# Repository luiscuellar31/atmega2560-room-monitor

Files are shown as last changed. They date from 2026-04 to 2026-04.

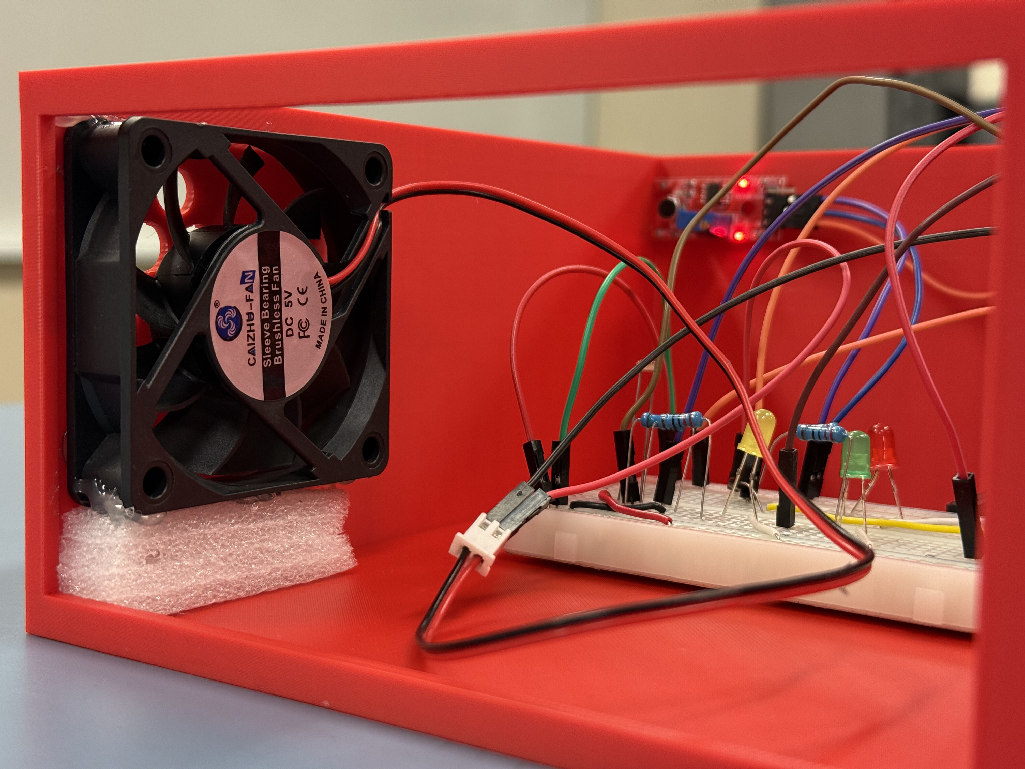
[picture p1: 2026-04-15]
img/monitor-box-fan.jpg

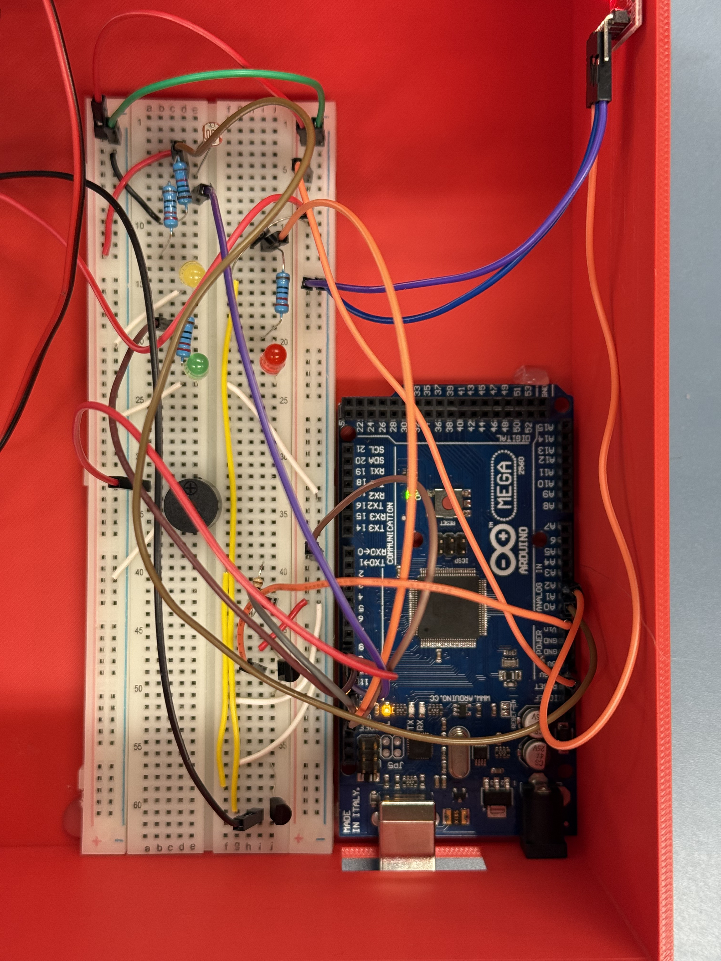
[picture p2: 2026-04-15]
img/monitor-box-up-zoom.jpg

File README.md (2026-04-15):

# ATmega2560 Smart Room Monitor

A simple embedded monitoring system built on the ATmega2560 using AVR Assembly.

## Overview

This project monitors environmental conditions in a small room or study-area model using three analog sensors:

- LM35 temperature sensor
- LDR light sensor
- KY-038 analog sound sensor

According to the detected conditions, the system activates different outputs:

- Red warning LED for high temperature
- Yellow warning LED for low light
- Green warning LED for sound events
- 5V cooling fan
- Active buzzer alarm

## Project Objective

The objective of this project was to design and implement an embedded room-monitoring prototype using the ATmega2560 and AVR Assembly, integrating analog sensing and actuator control under predefined alarm conditions.

This work was developed as part of my Embedded Systems course project.

## Main Features

- Reads three analog sensors through the ADC
- Controls LEDs, fan, and buzzer directly from the microcontroller
- Built almost entirely in AVR Assembly
- Works as a standalone embedded system without requiring a PC during operation

## System Logic

### Temperature
If temperature exceeds the configured threshold:
- Red LED turns on
- Fan turns on

### Light
If the environment is dark:
- Yellow LED turns on

### Sound
If a strong sound event is detected:
- Green LED turns on

To improve event visibility, the sound indicator now uses a short hold window:
- After a valid sound event, the green LED remains active briefly even if the next sample falls below threshold.

### Alarm Conditions
- If **three abnormal conditions** are active at the same time, the buzzer sounds intermittently while active condition LEDs remain on
- If **zero, one, or two abnormal conditions** are active, the buzzer stays off

## Hardware Used

- Arduino Mega 2560 / ATmega2560
- LM35
- LDR
- KY-038
- Active 5V buzzer
- 5V fan
- 2N2222 transistor
- 1N4007 diode
- LEDs
- Resistors
- Breadboard and jumper wires

## ADC Channels

- `A0` -> LM35
- `A1` -> LDR
- `A2` -> KY-038 analog output

## Output Pins

- `D12` -> Red temperature LED
- `D11` -> Fan control
- `D10` -> Yellow light warning LED
- `D9`  -> Green sound warning LED
- `D8`  -> Buzzer

## Notes

- Presentation files are available in [`docs/`](docs/).
- Build/reference photos are available in [`img/`](img/).
- The printable enclosure models are available in [`3d/`](3d/).
- The LDR was used as the sensor selected for the technical explanation of non-linear behavior.
- Threshold values were adjusted experimentally during testing.
- The sound sensor responds better to sharp nearby acoustic events than to continuous speech.
- Current firmware includes a short noise hold (`HOLD_RUIDO`) to avoid losing brief sound events between ADC cycles.

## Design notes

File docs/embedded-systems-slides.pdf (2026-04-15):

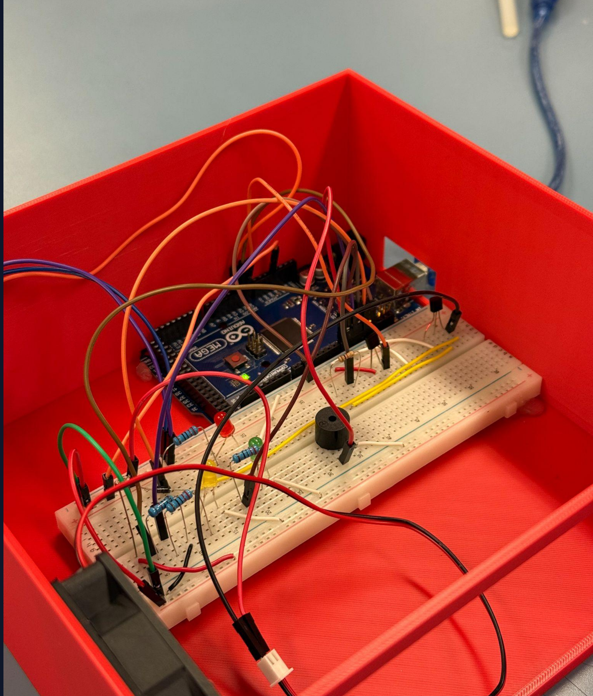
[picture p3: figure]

# Sistema de monitoreo ambiental con ATmega2560

Proyecto de sensores y actuadores programado en ensamblador AVR

Monitoreo de temperatura, iluminación y sonido.

Activación de LEDs, ventilador y buzzer ante condiciones específicas.

▹

▹

Luis Enrique Sánchez Cuellar Erick Daniel Alanis Inocencio

El proyecto busca emular una solución real de monitoreo ambiental usando el ATmega2560 y programación en ensamblador AVR.

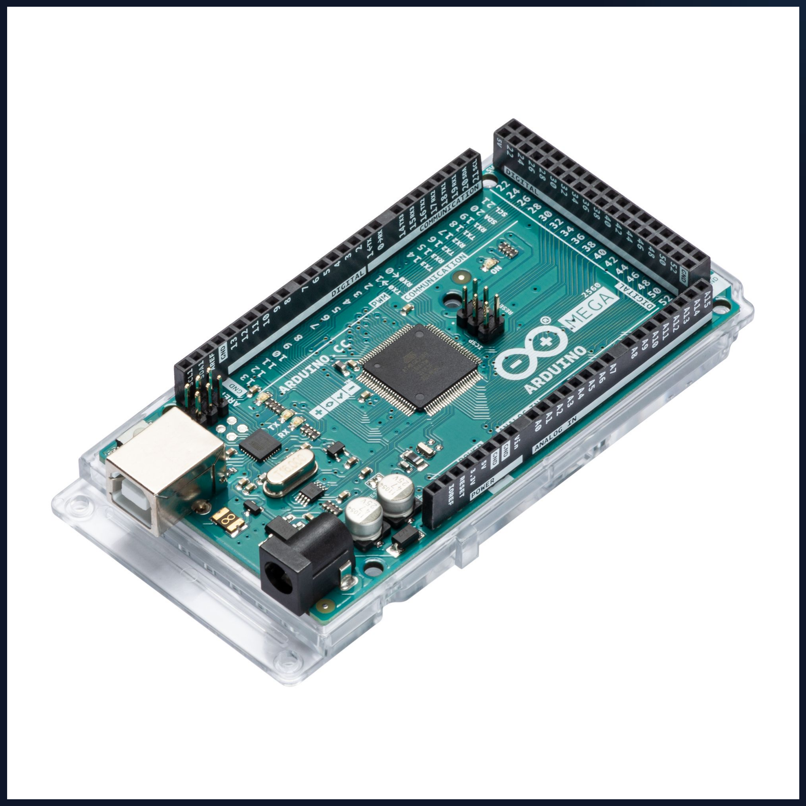
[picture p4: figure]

Diseñar un sistema embebido capaz de monitorear condiciones ambientales de una maqueta o zona de estudio.

Detectar tres variables analógicas del entorno:

Activar salidas de advertencia y respuesta automática según las condiciones medidas.

▹

▹

▹

Temperatura
Iluminación
Perturbaciones acústicas

•
•
•

# Objetivo del proyecto

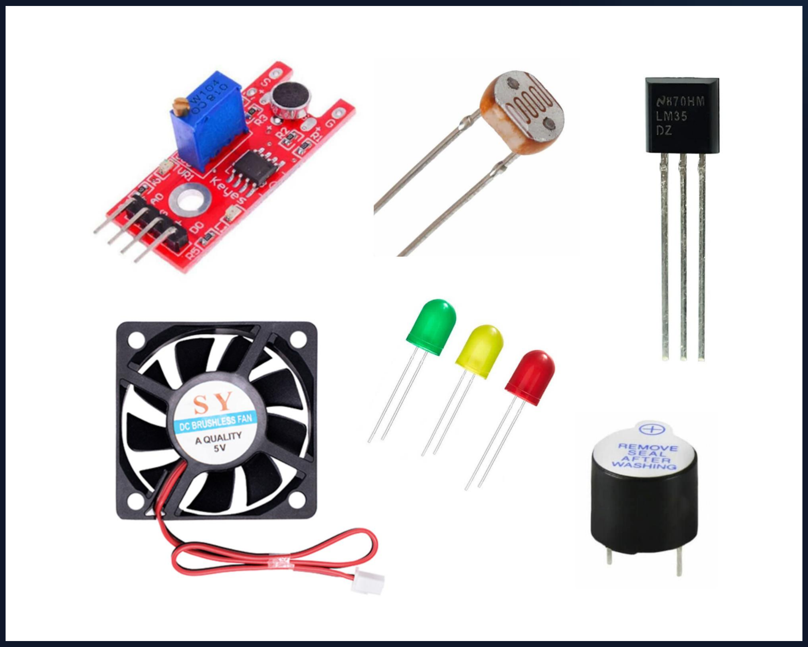
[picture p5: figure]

Sensores analógicos

Actuadores

- LM35 → temperatura
- LDR → iluminación
- KY-038 (salida AO) → perturbaciones acústicas
- LED verde → indicación de evento sonoro
- LED amarillo → indicación de oscuridad
- LED rojo → indicación de temperatura alta
- Ventilador 5V → respuesta ante temperatura alta
- Buzzer activo 5V → alarma crítica

# Sensores y actuadores utilizados

El sistema utiliza el ADC del ATmega2560 para convertir señales analógicas a valores digitales y compararlas con umbrales.

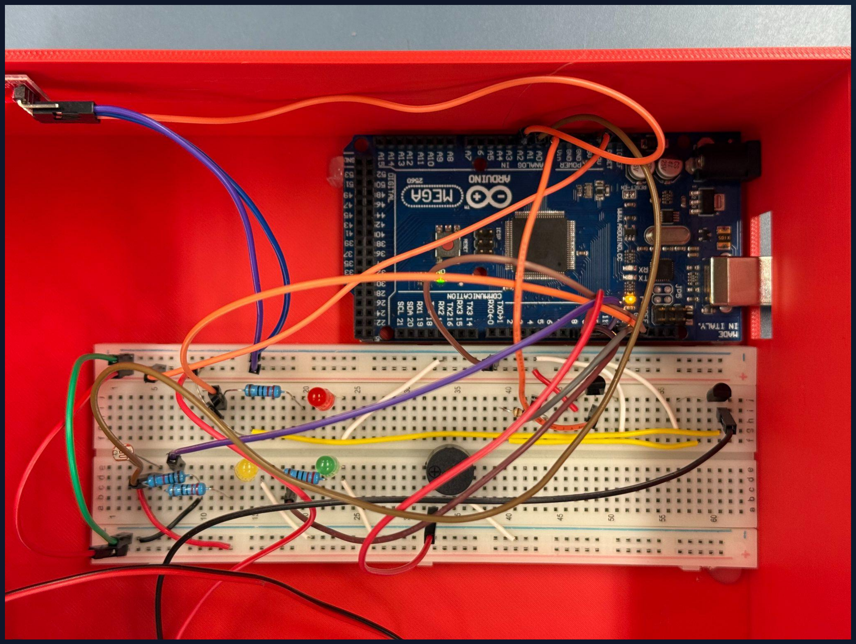
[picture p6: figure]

Entradas analógicas

# Conexión de sensores y salidas al ATmega2560

- A0 → LM35 - A1 → LDR - A2 → KY-038 (AO)

Salidas digitales

- D12 → LED de temperatura
- D11 → ventilador
- D10 → LED de oscuridad
- D9 → LED de ruido
- D8 → buzzer

El sistema utiliza el ADC del ATmega2560 para convertir señales analógicas en valores digitales y compararlas con umbrales definidos experimentalmente.

# Lógica de funcionamiento

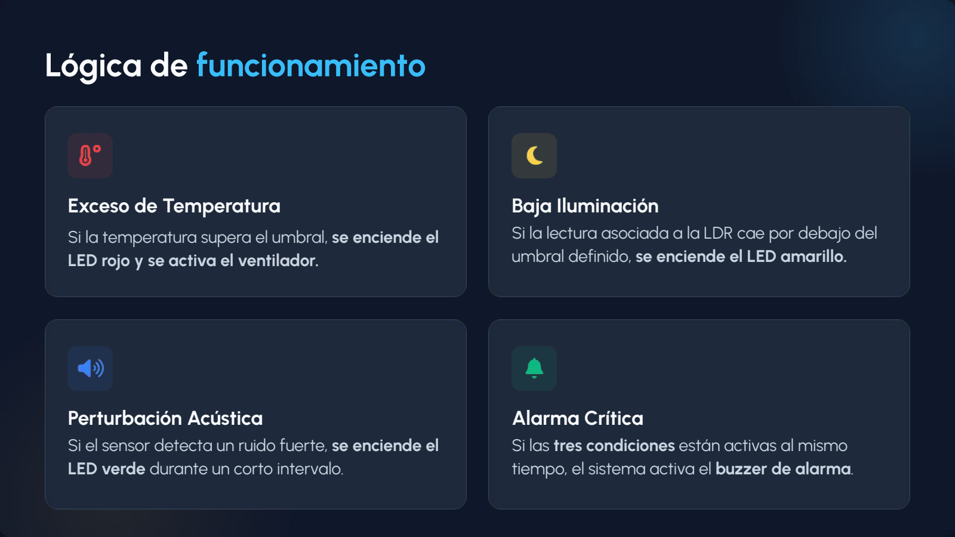
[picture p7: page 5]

Exceso de Temperatura
Si la temperatura supera el umbral, se enciende el LED rojo y se activa el ventilador.

Baja Iluminación
Si la lectura asociada a la LDR cae por debajo del umbral definido, se enciende el LED amarillo.

Perturbación Acústica
Si el sensor detecta un ruido fuerte, se enciende el LED verde durante un corto intervalo.

Alarma Crítica
Si las tres condiciones están activas al mismo tiempo, el sistema activa el buzzer de alarma.

# Descripción y comportamiento no lineal de una LDR

Sensor analógico empleado para detectar condiciones de iluminación. Integrado al ATmega2560 mediante un divisor de voltaje.

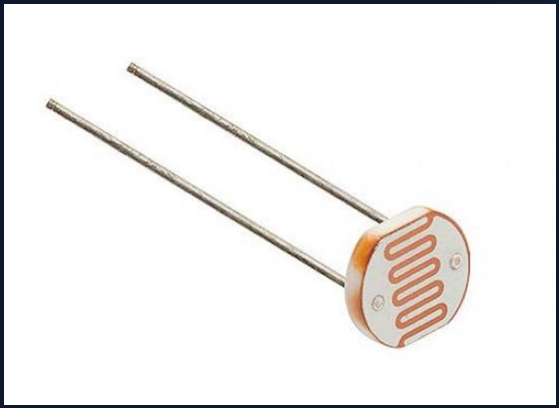
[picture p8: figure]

Una LDR (Light Dependent Resistor) o fotorresistencia es un componente cuya resistencia eléctrica depende de la luz que recibe.

Cuando la iluminación aumenta, su resistencia disminuye.

Cuando la iluminación disminuye, su resistencia aumenta.

Se utiliza para detectar cambios de iluminación de forma sencilla en sistemas y circuitos electrónicos.

▹

▹

▹

▹

# ¿Qué es una LDR?

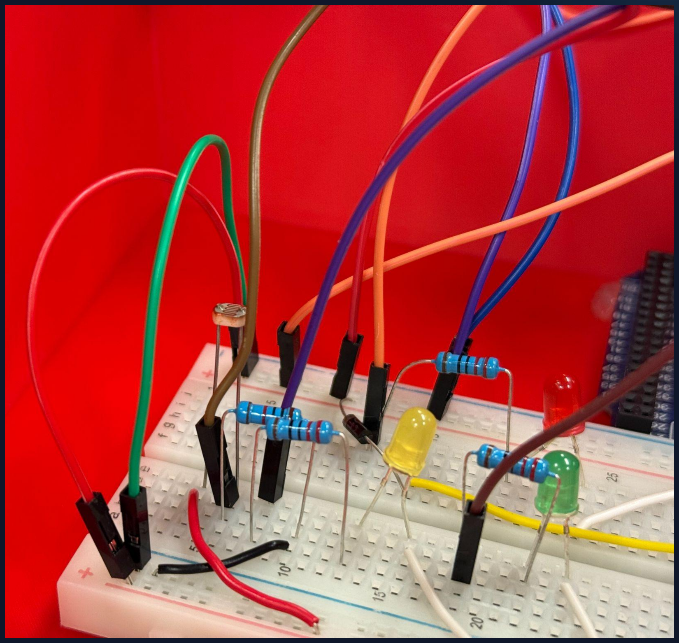
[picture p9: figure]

En el proyecto, la LDR se conectó en un divisor de voltaje con una resistencia fija de 10 kΩ.

El nodo intermedio del divisor se conectó a la entrada analógica A1 del ATmega2560.

El ADC del microcontrolador mide el voltaje resultante y lo compara con un umbral.

▹

▹

▹

# Principio del funcionamiento

De esta forma, el sistema puede detectar condiciones de baja iluminación a partir de la lectura del ADC.

▹

# Modelo eléctrico de la LDR en el circuito

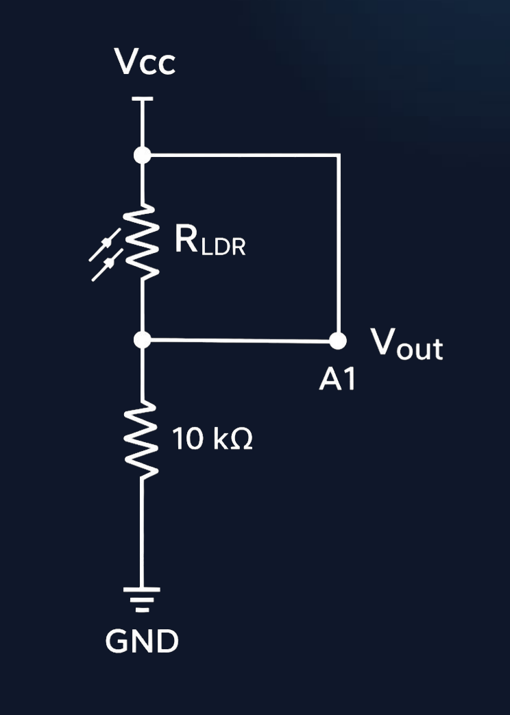
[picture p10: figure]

- La LDR no se mide directamente como resistencia.
- Se integra en un divisor de voltaje junto con una resistencia fija de 10 kΩ.
- El voltaje del nodo intermedio se conecta al pin A1 del ATmega2560.
- Así, las variaciones de resistencia de la LDR se transforman en variaciones de voltaje medibles por el ADC.

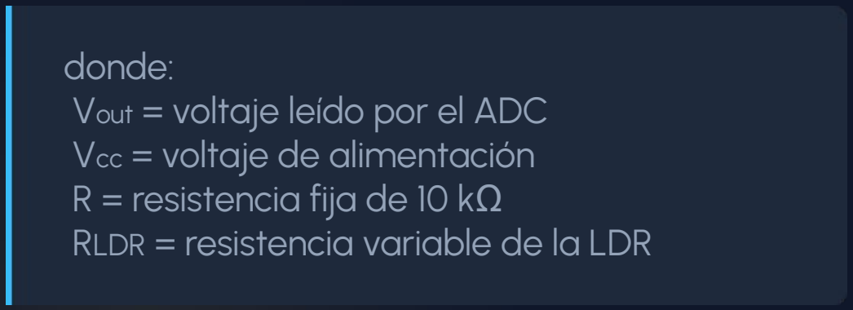
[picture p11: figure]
donde: Vout = voltaje leído por el ADC Vcc = voltaje de alimentación R = resistencia fija de 10 kΩ RLDR = resistencia variable de la LDR

La no linealidad del sensor obliga a ajustar experimentalmente el umbral de detección dentro del proyecto.

- La resistencia de una LDR no varía linealmente con la iluminación.
- En forma aproximada, su comportamiento puede modelarse mediante una relación de potencia:

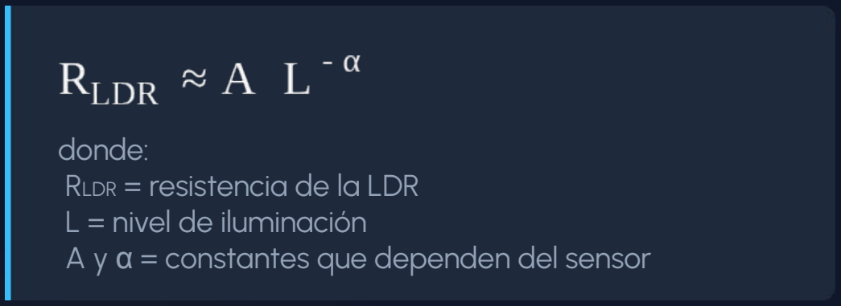
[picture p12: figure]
donde: RLDR = resistencia de la LDR L = nivel de iluminación

A y α = constantes que dependen del sensor

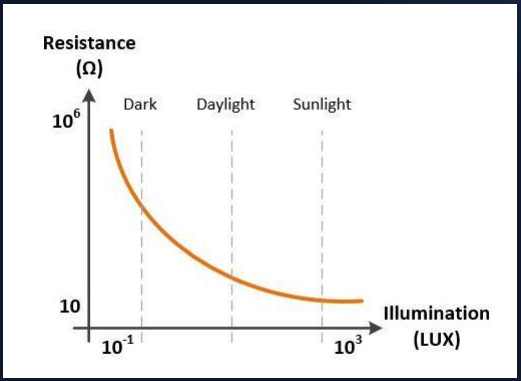
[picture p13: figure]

Esta ecuación muestra que la resistencia disminuye cuando la
iluminación aumenta, pero siguiendo una curva, no una recta.
Por ello, cambios iguales de luz no producen cambios iguales de resistencia ni de voltaje.
Debido a esta no linealidad, el umbral de activación del sistema tuvo que ajustarse experimentalmente.

▹

▹

# Ecuación y comportamiento no lineal de la LDR

# Comportamiento real en

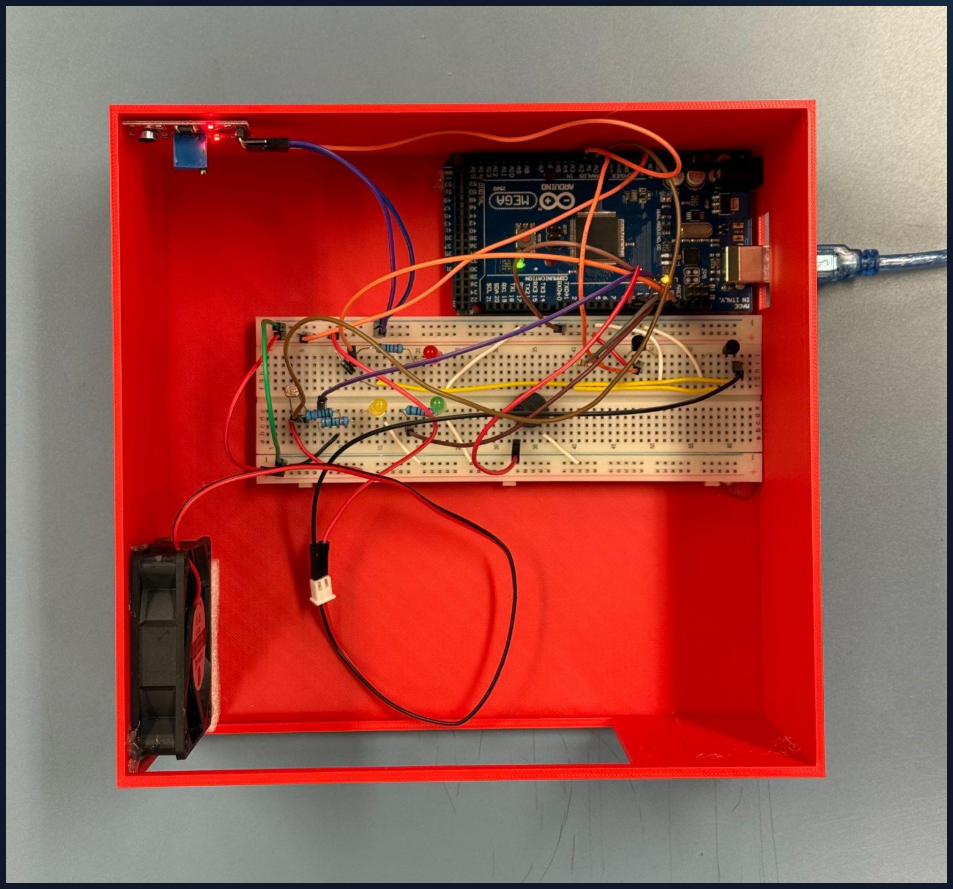
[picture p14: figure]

# el proyecto

En las pruebas del proyecto, la LDR respondió claramente a cambios de luz del entorno.

Con luz intensa (ej. flash del celular), la lectura cambió notablemente.

Al cubrir el sensor o cerrar la tapa de la maqueta, el sistema detectó la oscuridad y encendió el LED amarillo.
La respuesta dependió de factores físicos como:
- dirección de la luz,
- distancia de la fuente,
- cobertura parcial del sensor.

▹

▹

▹

▹

# Conclusión

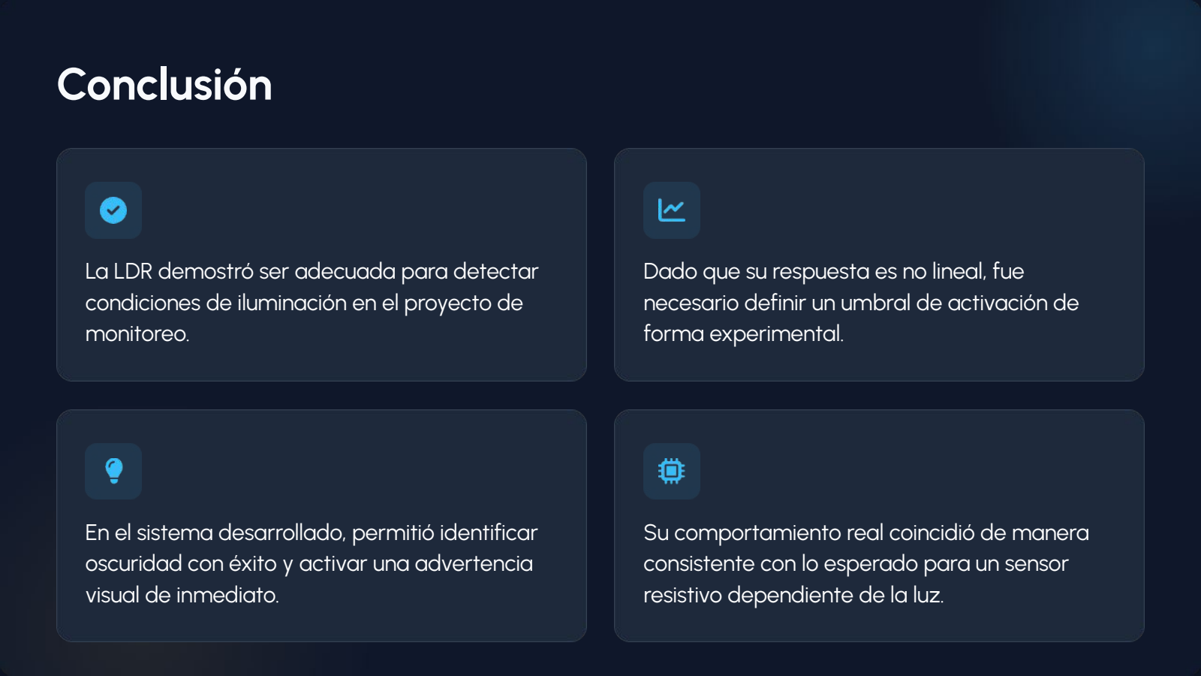
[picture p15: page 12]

La LDR demostró ser adecuada para detectar condiciones de iluminación en el proyecto de monitoreo.

Dado que su respuesta es no lineal, fue necesario definir un umbral de activación de forma experimental.

En el sistema desarrollado, permitió identificar oscuridad con éxito y activar una advertencia visual de inmediato.

Su comportamiento real coincidió de manera consistente con lo esperado para un sensor resistivo dependiente de la luz.

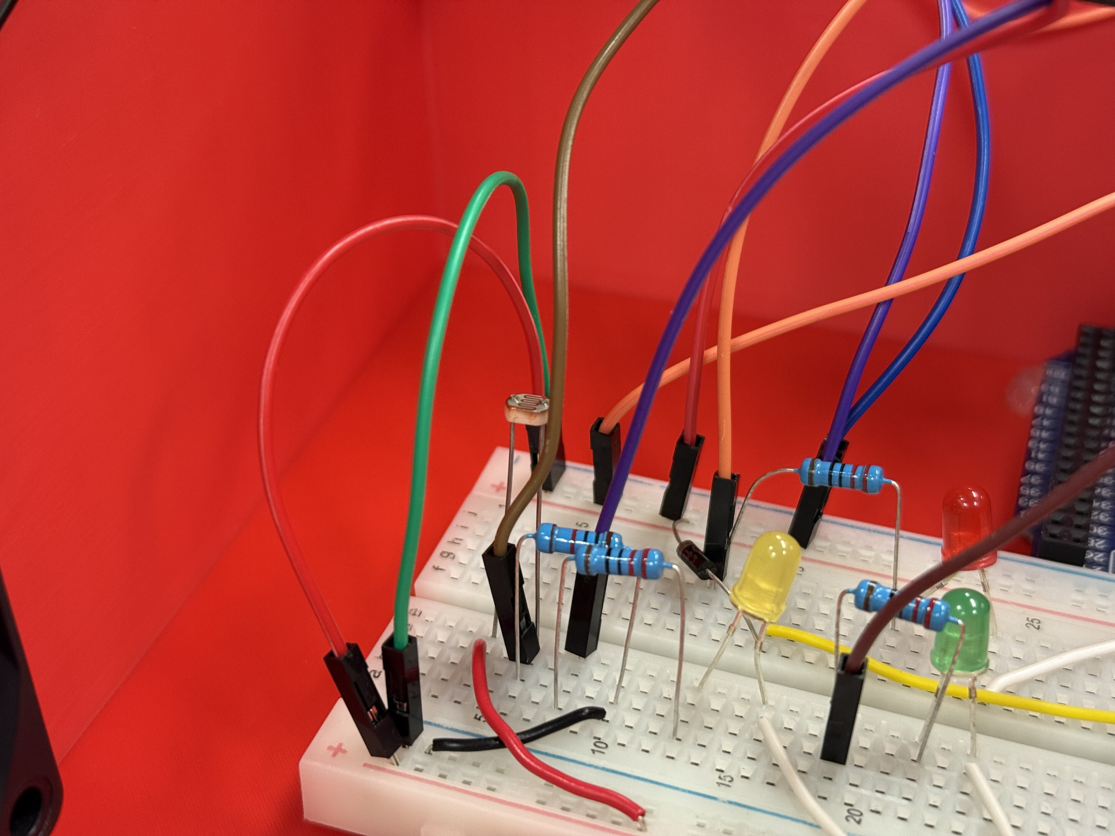
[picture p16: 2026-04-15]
img/monitor-box-ldr.jpg

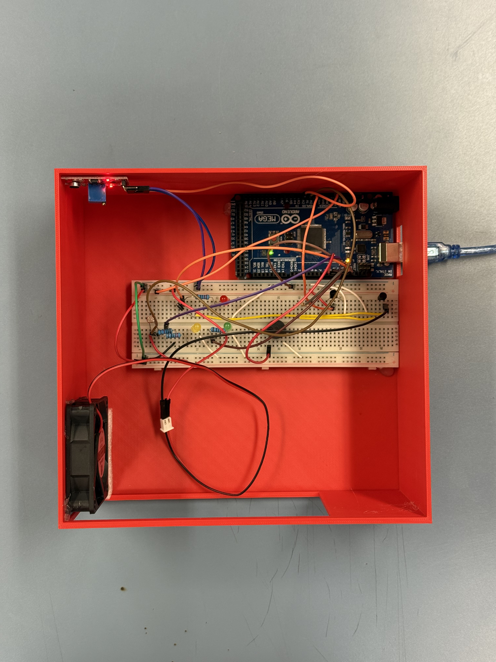
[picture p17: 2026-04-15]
img/monitor-box-up.jpg

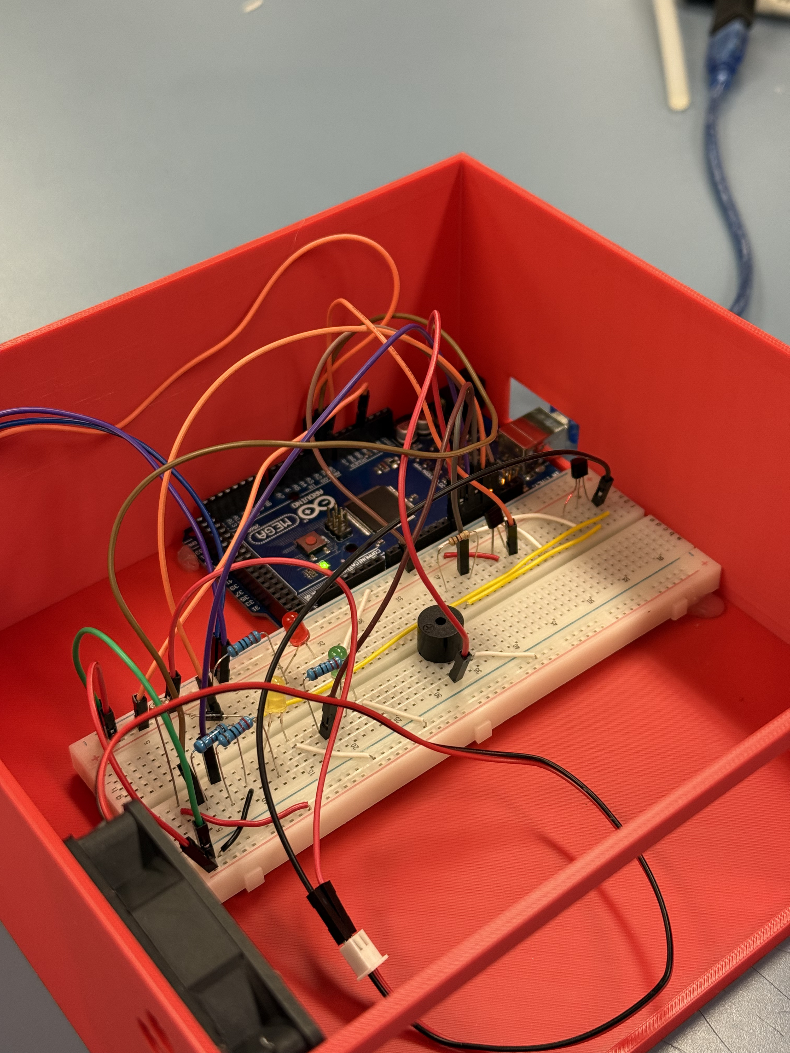
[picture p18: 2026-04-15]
img/monitor box-side.jpg

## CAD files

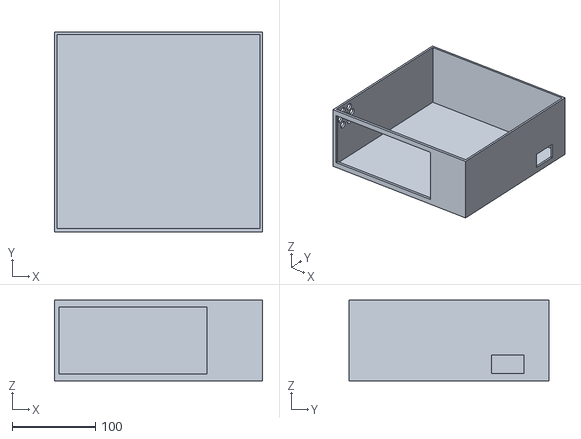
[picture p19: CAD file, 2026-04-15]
3d/room-monitor-box-open.stl
250.0 x 240.0 x 97.0

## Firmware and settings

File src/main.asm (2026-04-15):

.include "m2560def.inc"

; ==================================================
; Definición de registros de trabajo
; ==================================================
.def temp        = r16
.def adc_temp    = r17
.def adc_luz     = r18
.def adc_ruido   = r19
.def cont1       = r20
.def cont2       = r21
.def cont3       = r22
.def cond_count  = r23
.def ruido_hold  = r24

; ==================================================
; Umbrales de detección y retención de ruido
; ==================================================
.equ UMBRAL_TEMP   = 15
.equ UMBRAL_LUZ    = 65
.equ UMBRAL_RUIDO  = 15
.equ HOLD_RUIDO    = 20

; ==================================================
; Vector de reset
; ==================================================
.cseg
.org 0x0000
    rjmp RESET

RESET:
    ; Inicialización de pila
    ldi temp, high(RAMEND)
    out SPH, temp
    ldi temp, low(RAMEND)
    out SPL, temp

    ; Configuración de salidas:
    ; PB6 -> D12 -> LED temperatura
    ; PB5 -> D11 -> ventilador
    ; PB4 -> D10 -> LED de oscuridad
    sbi DDRB, 6
    sbi DDRB, 5
    sbi DDRB, 4

    ; PH6 -> D9  -> LED de ruido
    ; PH5 -> D8  -> buzzer
    lds temp, DDRH
    ori temp, (1<<6) | (1<<5)
    sts DDRH, temp

    ; Estado inicial de salidas en puerto B
    cbi PORTB, 6
    cbi PORTB, 5
    cbi PORTB, 4

    ; Estado inicial de salidas en puerto H
    lds temp, PORTH
    andi temp, 0b10011111
    sts PORTH, temp

    ; Inicialización de retención de ruido
    clr ruido_hold

    ; Configuración del ADC:
    ; Referencia AVcc
    ; Ajuste a la izquierda
    ; Lectura en ADCH
    ; Prescaler = 128
    ldi temp, (1<<REFS0) | (1<<ADLAR)
    sts ADMUX, temp

    ldi temp, (1<<ADEN) | (1<<ADPS2) | (1<<ADPS1) | (1<<ADPS0)
    sts ADCSRA, temp

LOOP:
    ; Reinicio de contador de condiciones activas
    clr cond_count

    ; ==================================================
    ; Lectura de temperatura en ADC0 (A0)
    ; ==================================================
    ldi temp, (1<<REFS0) | (1<<ADLAR) | 0
    sts ADMUX, temp

    lds temp, ADCSRA
    ori temp, (1<<ADSC)
    sts ADCSRA, temp

ESPERA_ADC_TEMP:
    lds temp, ADCSRA
    sbrc temp, ADSC
    rjmp ESPERA_ADC_TEMP

    lds adc_temp, ADCH

    cpi adc_temp, UMBRAL_TEMP
    brlo TEMP_BAJA

TEMP_ALTA:
    sbi PORTB, 6
    sbi PORTB, 5
    inc cond_count
    rjmp LEER_LUZ

TEMP_BAJA:
    cbi PORTB, 6
    cbi PORTB, 5

LEER_LUZ:
    ; ==================================================
    ; Lectura de luz en ADC1 (A1)
    ; ==================================================
    ldi temp, (1<<REFS0) | (1<<ADLAR) | 1
    sts ADMUX, temp

    lds temp, ADCSRA
    ori temp, (1<<ADSC)
    sts ADCSRA, temp

ESPERA_ADC_LUZ:
    lds temp, ADCSRA
    sbrc temp, ADSC
    rjmp ESPERA_ADC_LUZ

    lds adc_luz, ADCH

    cpi adc_luz, UMBRAL_LUZ
    brlo OSCURO

CLARO:
    cbi PORTB, 4
    rjmp LEER_RUIDO

OSCURO:
    sbi PORTB, 4
    inc cond_count

LEER_RUIDO:
    ; ==================================================
    ; Lectura de ruido en ADC2 (A2)
    ; ==================================================
    ldi temp, (1<<REFS0) | (1<<ADLAR) | 2
    sts ADMUX, temp

    lds temp, ADCSRA
    ori temp, (1<<ADSC)
    sts ADCSRA, temp

ESPERA_ADC_RUIDO:
    lds temp, ADCSRA
    sbrc temp, ADSC
    rjmp ESPERA_ADC_RUIDO

    lds adc_ruido, ADCH

    ; Si hay ruido real, recargar retención
    cpi adc_ruido, UMBRAL_RUIDO
    brlo REVISAR_HOLD_RUIDO

CON_RUIDO_REAL:
    ldi ruido_hold, HOLD_RUIDO

    lds temp, PORTH
    ori temp, (1<<6)
    sts PORTH, temp

    inc cond_count
    rjmp EVALUAR_ALARMA

REVISAR_HOLD_RUIDO:
    cpi ruido_hold, 0
    breq SIN_RUIDO

    dec ruido_hold

    lds temp, PORTH
    ori temp, (1<<6)
    sts PORTH, temp

    inc cond_count
    rjmp EVALUAR_ALARMA

SIN_RUIDO:
    lds temp, PORTH
    andi temp, 0b10111111
    sts PORTH, temp

EVALUAR_ALARMA:
    ; ==================================================
    ; Lógica de alarma general
    ;
    ; 3 condiciones:
    ;   - LEDs permanecen encendidos
    ;   - buzzer intermitente
    ;
    ; 0, 1 o 2 condiciones:
    ;   - buzzer apagado
    ; ==================================================
    cpi cond_count, 3
    breq ALARMA_TOTAL

    rjmp BUZZER_OFF

ALARMA_TOTAL:
    ; Mantener encendidos los LEDs ya activados
    ; Activar buzzer de forma intermitente
    lds temp, PORTH
    ori temp, (1<<5)
    sts PORTH, temp

    rcall RETARDO_BUZZER

    lds temp, PORTH
    andi temp, 0b11011111
    sts PORTH, temp

    rcall RETARDO_BUZZER

    rjmp LOOP

BUZZER_OFF:
    ; Buzzer apagado con 0, 1 o 2 condiciones
    lds temp, PORTH
    andi temp, 0b11011111
    sts PORTH, temp

    ; Si hay ruido activo, mantenerlo visible un poco
    cpi ruido_hold, 0
    breq FIN_LOOP

    rcall RETARDO_RUIDO

FIN_LOOP:
    rjmp LOOP

; ==================================================
; Retardo corto para mantener visible el LED de ruido
; ==================================================
RETARDO_RUIDO:
    ldi cont1, 40

RR1:
    ldi cont2, 255

RR2:
    ldi cont3, 255

RR3:
    dec cont3
    brne RR3

    dec cont2
    brne RR2

    dec cont1
    brne RR1

    ret

; ==================================================
; Retardo para buzzer intermitente
; ==================================================
RETARDO_BUZZER:
    ldi cont1, 50

RB1:
    ldi cont2, 255

RB2:
    ldi cont3, 255

RB3:
    dec cont3
    brne RB3

    dec cont2
    brne RB2

    dec cont1
    brne RB1

    ret

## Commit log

2026-04-14 feat(firmware): initialize stack and blink PB7 LED with software delay
2026-04-14 style(firmware): improve comments and formatting in main assembly
2026-04-14 feat(firmware): read ADC0 and drive D12 LED based on threshold
2026-04-14 feat(firmware): control LED and fan outputs from ADC threshold
2026-04-14 feat(firmware): add multi-sensor ADC monitoring and conditional alarm logic
2026-04-15 chore(3d): add enclosure STL files and document them in README
    [room-monitor-box.stl, room-monitor-lid.stl]
2026-04-15 docs(readme): correct LED color mapping for temperature, light, and sound
2026-04-15 feat(3d): add v2 open-top enclosure box model
    [room-monitor-box-v2-open.stl]
2026-04-15 feat(firmware): lower light and noise detection thresholds
    [main.asm]
2026-04-15 chore(3d): refresh enclosure STL models
    [room-monitor-box-open.stl, room-monitor-box.stl, room-monitor-lid.stl]
2026-04-15 docs(media): add room monitor enclosure photos
2026-04-15 docs(readme): simplify enclosure reference in notes section
